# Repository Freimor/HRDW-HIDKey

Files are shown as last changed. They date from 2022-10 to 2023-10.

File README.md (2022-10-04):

## HID Key
A HID device for loadout system with a setup script. Made for the OPS team of School 21. This device allows to easily set up new workstations with just one keychain-like device. Before that the team used Arduino Micro with a bulky case and a usb cable. That device connects to MAC via Type-C, it is protected from electrostatic discharge, has an additional programmable button, an RGB LED and is very small in size.

The project is completed in Q3 2021.

 

## Parameters for PCB order (JLCPCB compatible)
2 layer board

0.8mm thickness

0.3mm min hole size

## BOM list
| №  | Designator | Qty | Description | Manufacturer | Name | Package | Link |
| -- | --- | --- | --- | --- | --- | --- | ---- |
| 1  | C1 | 1 | 10uf MLCC | | | 0402 | |
| 2  | C2,C3 | 2 | 14pf MLCC | | | 0402 | |
| 3  | C4,C5,C7,C9,C10 | 5 | 100nf MLCC | | | 0402 | |
| 4  | C6,C8 | 2 | 1uf MLCC | | | 0402 | |
| 5  | R1 | 1 | 1MΩ smd | | | 0402 | |
| 6  | R2 | 1 | 5.1kΩ smd | | | 0402 | |
| 7  | R3,R4 | 2 | 22Ω smd | | | 0402 | |
| 8  | R5,R6,R12 | 3 | 10kΩ smd | | | 0402 | |
| 9  | R7,R8,R9,R10,R11| 5 | 1kΩ smd | | | 0402 | |
| 10 | D1 | 1 | ESD protection chip | Nexperia | IP4220CZ6 | TSOP6 | |
| 11 | D2 | 1 | Yellow smd led | | | 0402 | |
| 12 | D3 | 1 | Green smd led | | | 0402 | |
| 13 | D4 | 1 | RGB smd led | Foshan NationStar | FM-B2020RGBA-HG| 2020 | |
| 14 | J1 | 1 | USB Type-C 24pin | XKB Connectivity  | U261-241N-4BS60| | |
| 15 | SW1, SW2 | 2 | Tactile switch | KLS Electronic | KLS7-TS5401 | | |
| 16 | U1 | 1 | 8bit microcontroller| Atmel | ATmega32u4 | QFN44 | |
| 17 | Y1 | 1 | 16mhz crystal | CREC | | SMD02520C4| |

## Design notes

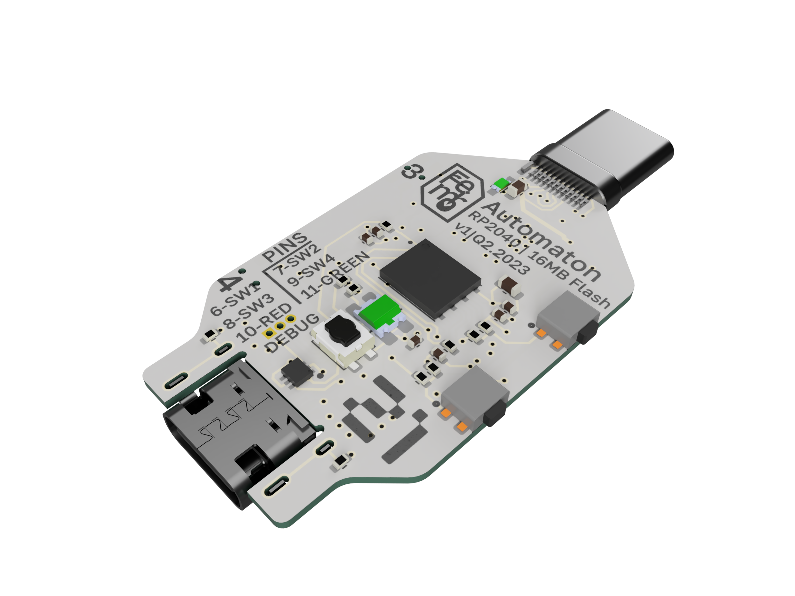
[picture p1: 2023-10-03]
KiCad/HID_Key_v2/usbduck_render_back.png

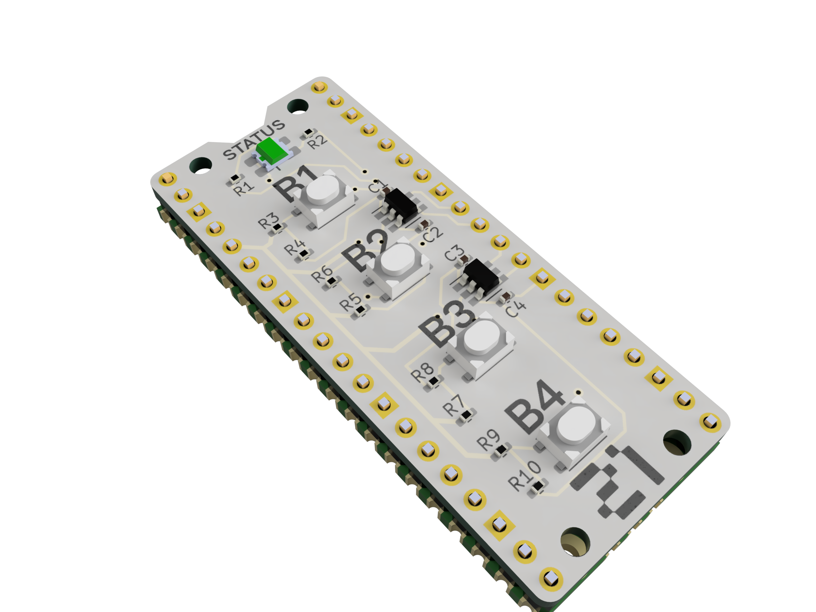
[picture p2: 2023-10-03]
KiCad/HID_Key_PicoMod/Pico_mod_render_1.PNG

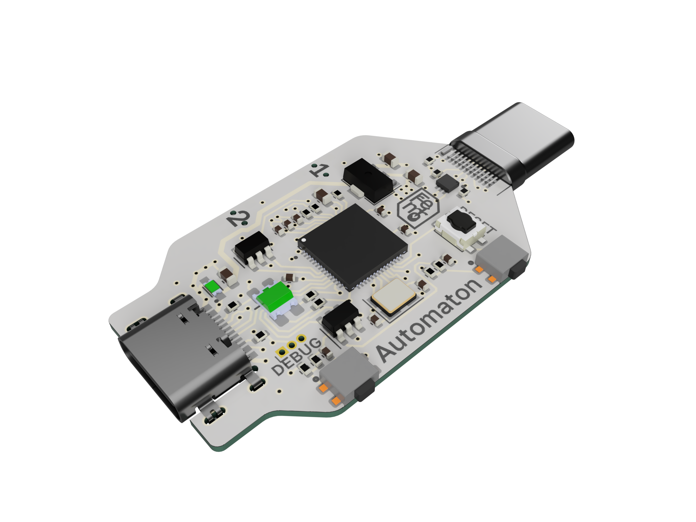
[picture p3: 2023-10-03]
KiCad/HID_Key_v2/usbduck_render_front.PNG

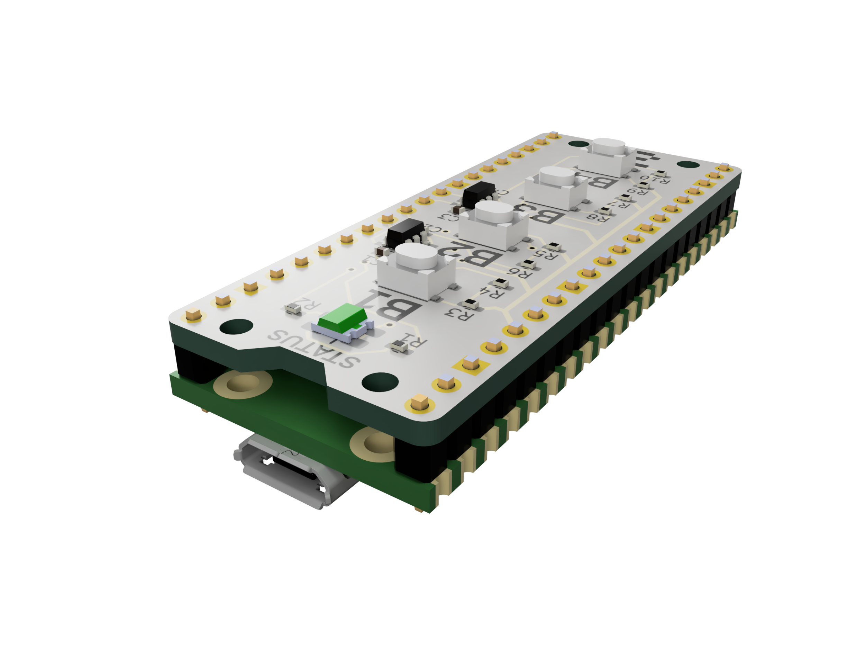
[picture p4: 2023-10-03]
KiCad/HID_Key_PicoMod/Pico_mod_render_2.png

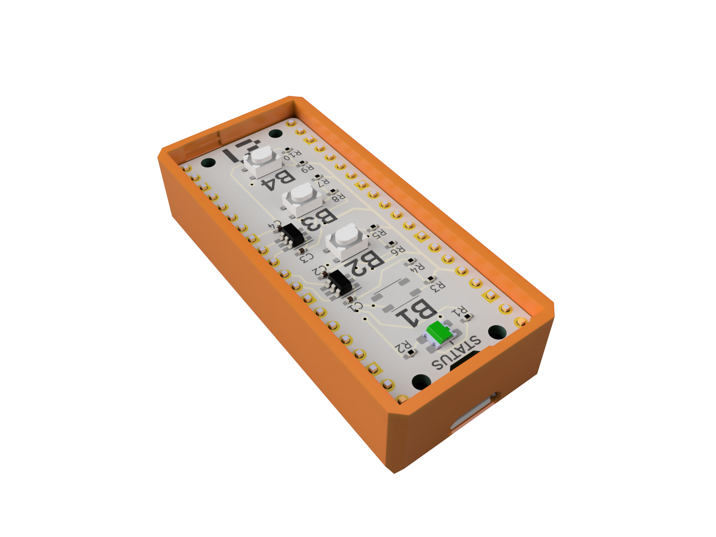
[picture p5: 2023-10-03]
KiCad/HID_Key_PicoMod/Pico_mod_render_3.png

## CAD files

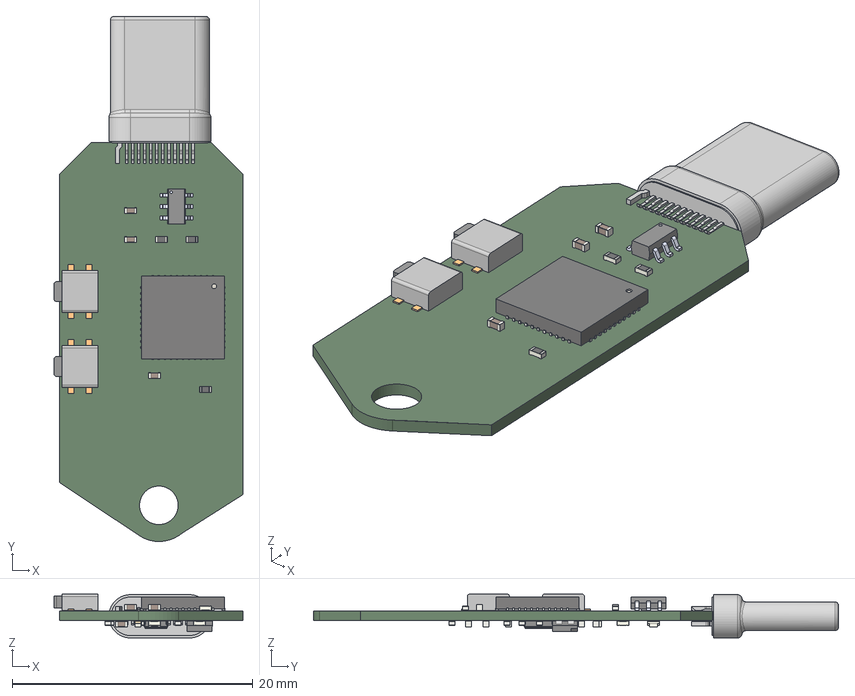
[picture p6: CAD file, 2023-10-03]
3d Model/HIDKey_v1.step
15.7 x 43.6 x 3.65 mm
Bocal_HIDKey PCB

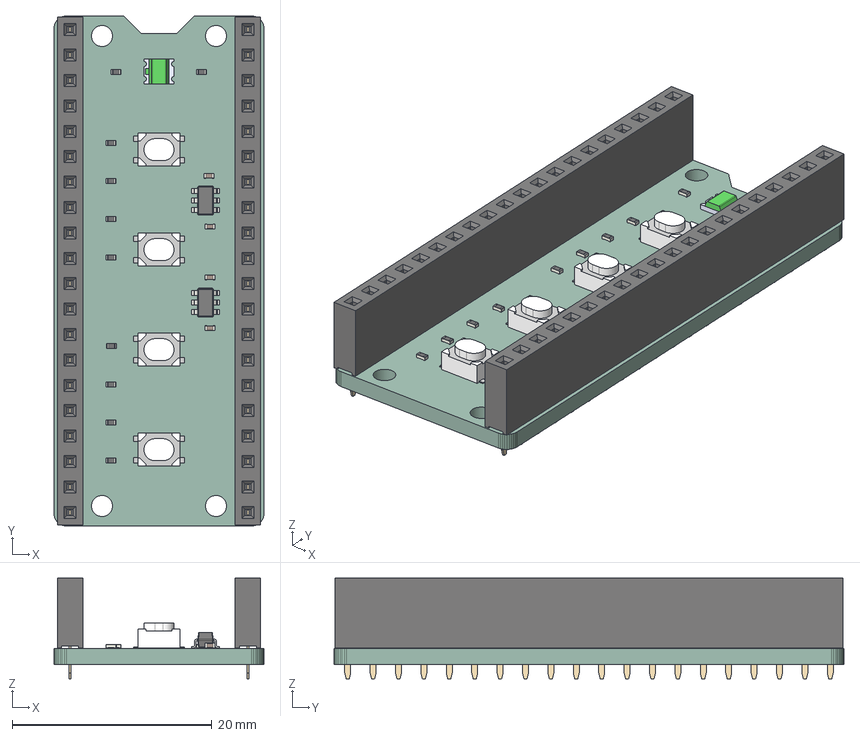
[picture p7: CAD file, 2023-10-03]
KiCad/HID_Key_PicoMod/Pico_mod.step
21.0 x 51.0 x 10.1 mm
Pico_mod PCB

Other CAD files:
3d Model/HIDKey_v1.f3d
3d Model/HIDKey_v2.f3d

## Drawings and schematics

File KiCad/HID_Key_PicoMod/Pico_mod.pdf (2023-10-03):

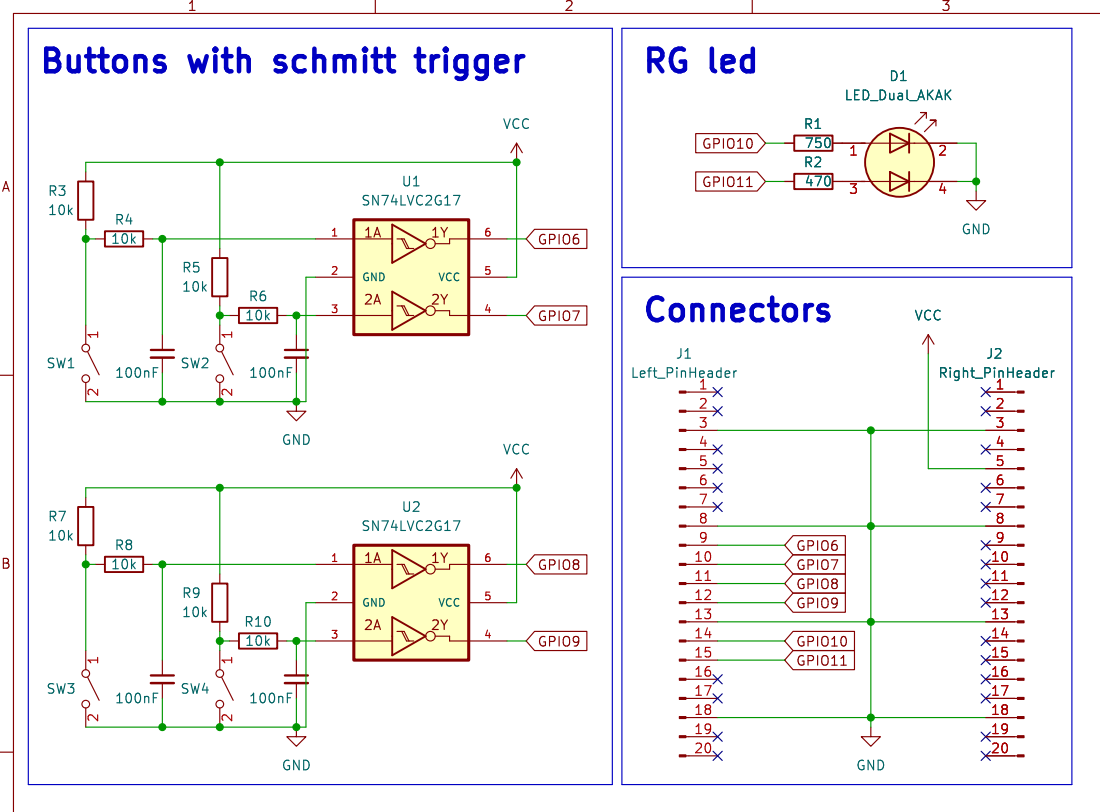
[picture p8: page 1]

Id: 1/1 Title: File: Pico_mod.kicad_sch Sheet: /

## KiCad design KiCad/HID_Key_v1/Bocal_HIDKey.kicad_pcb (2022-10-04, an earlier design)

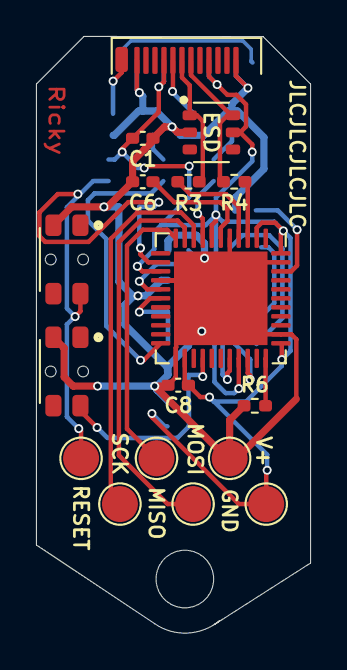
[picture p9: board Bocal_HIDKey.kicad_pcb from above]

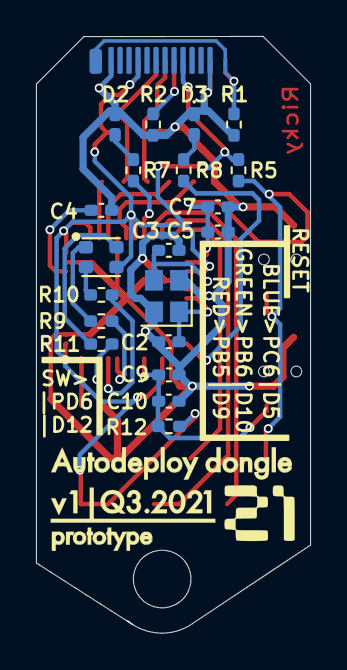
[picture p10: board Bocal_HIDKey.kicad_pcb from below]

Board: 2 copper layers, 15.2 x 33.1 mm, 37 parts (20 on the bottom side), 28 nets.

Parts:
C1: 10uF; C_0402_1005Metric_Pad0.74x0.62mm_HandSolder
C2, C3: 14pF; C_0402_1005Metric_Pad0.74x0.62mm_HandSolder
C4, C5, C7, C9, C10: 100n; C_0402_1005Metric_Pad0.74x0.62mm_HandSolder
C6, C8: 1uF; C_0402_1005Metric_Pad0.74x0.62mm_HandSolder
D1: IP4220CZ6
D2: RXLED; LED_0402_1005Metric_Pad0.77x0.64mm_HandSolder
D3: TXLED; LED_0402_1005Metric_Pad0.77x0.64mm_HandSolder
D4: LED_RBAG; LED_RGB_FM-B2020RGBA-HG
GND: test_pad_circle2mm; Pad_test
J1: USB_C_Receptacle_USB2.0; USB_C_U261-24XN-4BS60
MISO: test_pad_circle2mm; Pad_test
MOSI: test_pad_circle2mm; Pad_test
R1: 1M; R_0402_1005Metric_Pad0.72x0.64mm_HandSolder
R2: 5K1; R_0402_1005Metric_Pad0.72x0.64mm_HandSolder
R3, R4: 22; R_0402_1005Metric_Pad0.72x0.64mm_HandSolder
R5, R6, R12: 10K; R_0402_1005Metric_Pad0.72x0.64mm_HandSolder
R7, R8, R9, R10, R11: 1K; R_0402_1005Metric_Pad0.72x0.64mm_HandSolder
RESET: test_pad_circle2mm; Pad_test
SCK: test_pad_circle2mm; Pad_test
SW1: RESET_SW; TacSW_KLS7-TS5401
SW2: USER_SW; TacSW_KLS7-TS5401
U1: ATmega32U4-MU; QFN-44-1EP_7x7mm_P0.5mm_EP5.2x5.2mm
V+: test_pad_circle2mm; Pad_test
Y1: Crystal_GND24_Small; Crystal_SMD_2520-4Pin_2.5x2.0mm

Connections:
D+: D1.1, J1.A6, R3.2
D-: D1.6, J1.A7, R4.2
GND: C1.2, C2.2, C3.2, C4.2, C5.1, C6.2, C7.1, C8.2, C9.1, C10.1, D1.2, D2.1 (K), D3.1 (K), GND.1, J1.A1, J1.A12, J1.B1, J1.B12, R1.1, R2.2, R6.1, SW1.3, SW2.3, U1.5 (UGND), U1.15 (GND), U1.23 (GND), U1.35 (GND), U1.43 (GND), U1.45 (GND), Y1.2, Y1.4
MISO: MISO.1, U1.11 (PB3)
MOSI: MOSI.1, U1.10 (PB2)
unnamed: C2.1, U1.17 (XTAL1), Y1.1
unnamed: C3.1, U1.16 (XTAL2), Y1.3
unnamed: C4.1, U1.42 (AREF)
unnamed: C6.1, U1.6 (UCAP)
unnamed: C9.2, C10.2, R12.2, SW2.2, U1.26 (PD6)
unnamed: D2.2 (A), R7.1
unnamed: D3.2 (A), R8.1
unnamed: D4.1 (RK), R9.1
unnamed: D4.2 (BK), R11.1
unnamed: D4.4 (GK), R10.1
unnamed: J1.A5, R2.1
unnamed: J1.S1, R1.2
unnamed: R3.1, U1.4 (D+)
unnamed: R4.1, U1.3 (D-)
unnamed: R6.2, U1.33 (~HWB/PE2)
unnamed: R7.2, U1.8 (PB0)
unnamed: R8.2, U1.22 (PD5)
unnamed: R9.2, U1.29 (PB5)
unnamed: R10.2, U1.30 (PB6)
unnamed: R11.2, U1.31 (PC6)
RESET: C5.2, C7.2, R5.2, RESET.1, SW1.2, U1.13 (~RESET)
SCK: SCK.1, U1.9 (PB1)
VBUS: C1.1, C8.1, D1.5, D4.3 (A), J1.A4, J1.A9, J1.B4, J1.B9, R5.1, R12.1, U1.2 (UVCC), U1.7 (VBUS), U1.14 (VCC), U1.24 (AVCC), U1.34 (VCC), U1.44 (AVCC), V+.1

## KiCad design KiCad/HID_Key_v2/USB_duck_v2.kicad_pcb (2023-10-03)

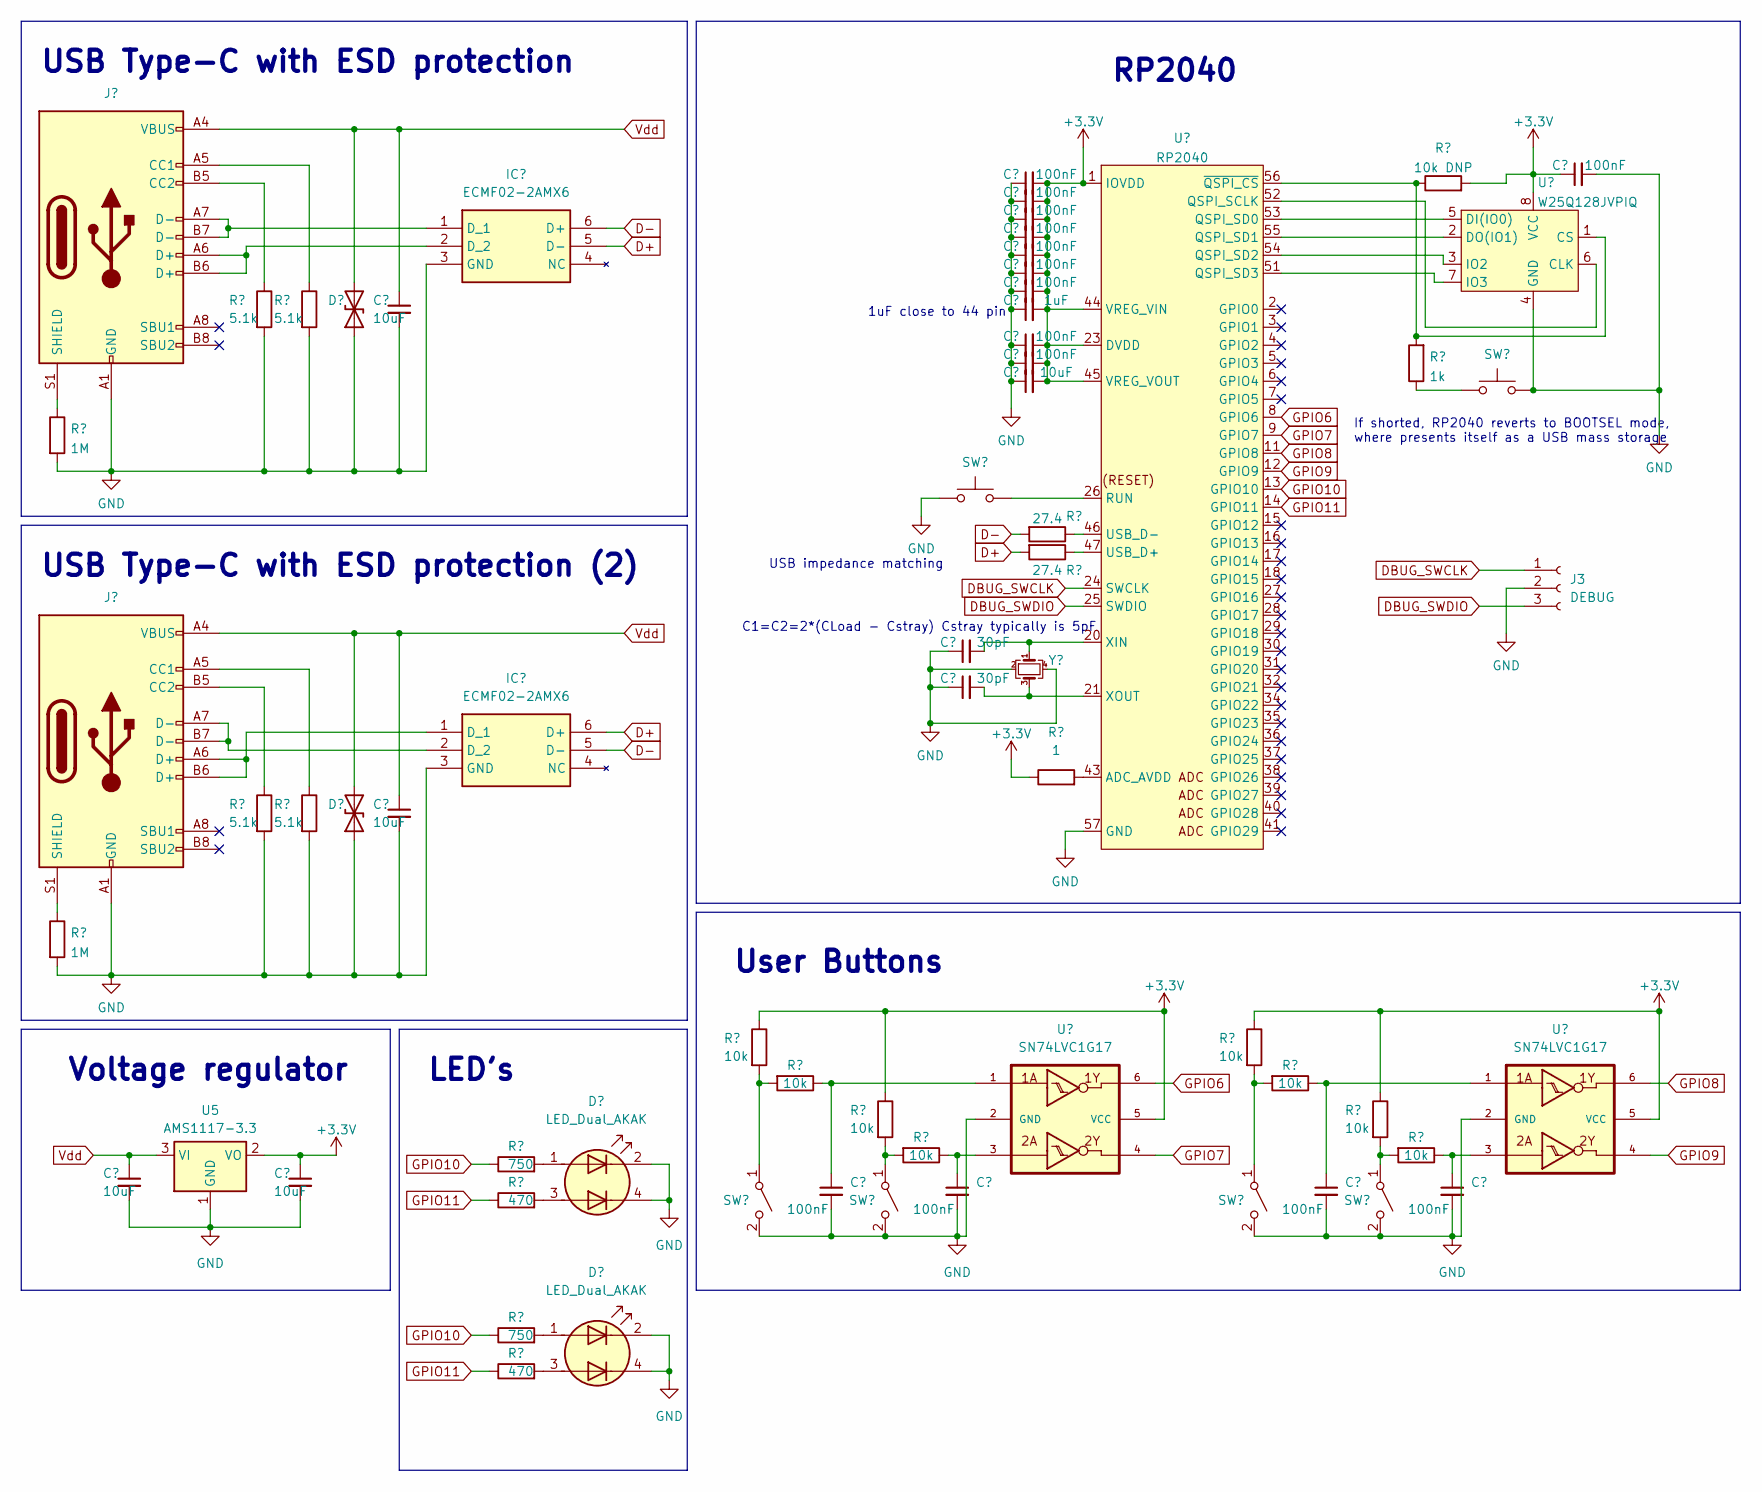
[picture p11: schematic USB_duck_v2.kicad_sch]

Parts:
BOOTSEL1: BOOTSEL; SW_SMD_XKB_(TS-1809SM-C)
C1, C2, C3, C4, C5, C6, C7, C8, C11, C12, C19, C20, C21, C22: 100nF; C_0402_1005Metric
C9, C13, C16, C17, C18: 10uF; C_0603_1608Metric
C10: 1uF; C_0603_1608Metric
C14, C15: 30pF; C_0402_1005Metric
D1, D2: D_TVS; ESD_PGB1010603MR
D3, D4: LED_Dual_AKAK; LED_RG_KPB-3025
IC1, IC2: ECMF02-2AMX6; ESD_ECMF02-2AMX6; Manufacturer_Part_Number ECMF02-2AMX6; Mouser Part Number 511-ECMF02-2AMX6
J1: USB_C_Receptacle_USB2.0; XKB_TYPE-C-U261-241N-4BS60
J2: USB_C_Receptacle_USB2.0; GCT_TYPE-C-USB4505-03-0-A
J3: DEBUG; PinHeader_1x03_P1.00mm_Vertical
R1: 10k DNP; R_0402_1005Metric
R2, R3, R9, R10: 5.1k; R_0402_1005Metric
R4: 1k; R_0402_1005Metric
R5, R11: 1M; R_0402_1005Metric
R6, R7: 27.4; R_0402_1005Metric
R8: 1; R_0402_1005Metric
R12, R13, R14, R15, R16, R17, R18, R19: 10k; R_0402_1005Metric
R20, R22: 750; R_0402_1005Metric
R21, R23: 470; R_0402_1005Metric
SW1: SW_Push; SW_SMD_XKB_(TS-1809SM-C)
SW2, SW3, SW4, SW5: SW_SPST; SW_SMD_KLS7-TS5401
U1: RP2040; MK_RP2040
U2: W25Q128JVPIQ; FLASH_W25Q128JVPIQ
U3, U4: SN74LVC1G17; SOT-23-6
U5: AMS1117-3.3; SOT-89-3
Y1: Crystal_GND24_Small; Crystal_SMD_3225-4Pin_3.2x2.5mm

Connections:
+3V3: C1.1, C2.2, C3.2, C4.2, C5.2, C6.2, C7.2, C8.2, C10.2, C11.2, C12.2, C13.2, C18.1, R1.2, R8.1, R12.1, R13.1, R16.1, R17.1, U1.1 (IOVDD), U1.10 (IOVDD), U1.22 (IOVDD), U1.23 (DVDD), U1.33 (IOVDD), U1.42 (IOVDD), U1.44 (VREG_VIN), U1.45 (VREG_VOUT), U1.48 (USB_VDD), U1.49 (IOVDD), U1.50 (DVDD), U2.8 (VCC), U3.5 (VCC), U4.5 (VCC), U5.2 (VO)
D+: IC1.5 (D-), IC2.6 (D+), R7.2
D-: IC1.6 (D+), IC2.5 (D-), R6.2
DBUG_SWCLK: J3.1, U1.24 (SWCLK)
DBUG_SWDIO: J3.3, U1.25 (SWDIO)
GND: BOOTSEL1.2, C1.2, C2.1, C3.1, C4.1, C5.1, C6.1, C7.1, C8.1, C9.2, C10.1, C11.1, C12.1, C13.1, C14.1, C15.1, C16.2, C17.2, C18.2, C19.2, C20.2, C21.2, C22.2, D1.1 (A1), D2.1 (A1), D3.2 (K1), D3.4 (K2), D4.2 (K1), D4.4 (K2), IC1.3 (GND), IC2.3 (GND), J1.A1 (GND), J1.A12 (GND), J1.B1 (GND), J1.B12 (GND), J2.A1 (GND), J2.A12 (GND), J2.B1 (GND), J2.B12 (GND), J3.2, R2.2, R3.2, R5.2, R9.2, R10.2, R11.2, SW1.1, SW2.2 (B), SW3.2 (B), SW4.2 (B), SW5.2 (B), U1.19 (TESTEN), U1.57 (GND), U2.4 (GND), U3.2 (GND), U4.2 (GND), U5.1 (GND), Y1.2, Y1.4; also elsewhere on the board
GPIO6: U1.8 (GPIO6), U3.6
GPIO7: U1.9 (GPIO7), U3.4
GPIO8: U1.11 (GPIO8), U4.6
GPIO9: U1.12 (GPIO9), U4.4
GPIO10: R20.1, R22.1, U1.13 (GPIO10)
GPIO11: R21.1, R23.1, U1.14 (GPIO11)
unnamed: BOOTSEL1.1, R4.1
unnamed: C19.1, R14.1, U3.1
unnamed: C20.1, R18.1, U3.3
unnamed: C21.1, R15.1, U4.1
unnamed: C22.1, R19.1, U4.3
unnamed: D3.1 (A1), R20.2
unnamed: D3.3 (A2), R21.2
unnamed: D4.1 (A1), R22.2
unnamed: D4.3 (A2), R23.2
unnamed: IC1.1 (D_1), J1.A7 (D-), J1.B7 (D-)
unnamed: IC1.2 (D_2), J1.A6 (D+), J1.B6 (D+)
unnamed: IC2.1 (D_1), J2.A6 (D+), J2.B6 (D+)
unnamed: IC2.2 (D_2), J2.A7 (D-), J2.B7 (D-)
unnamed: J1.A5 (CC1), R3.1
unnamed: J1.B5 (CC2), R2.1
unnamed: J1.S1 (SHIELD), R5.1
unnamed: J2.A5 (CC1), R10.1
unnamed: J2.B5 (CC2), R9.1
unnamed 30: J2.S1 (SHIELD), R11.1; also elsewhere on the board
unnamed: R12.2, R14.2, SW2.1 (A)
unnamed: R16.2, R18.2, SW3.1 (A)
unnamed: R13.2, R15.2, SW4.1 (A)
unnamed: R17.2, R19.2, SW5.1 (A)
unnamed: R8.2, U1.43 (ADC_AVDD)
unnamed: U1.52 (QSPI_SCLK), U2.6 (CLK)
unnamed: U1.53 (QSPI_SD0), U2.5 (DI(IO0))
unnamed: U1.55 (QSPI_SD1), U2.2 (DO(IO1))
unnamed: U1.54 (QSPI_SD2), U2.3 (IO2)
unnamed: U1.51 (QSPI_SD3), U2.7 (IO3)
unnamed: SW1.2, U1.26 (RUN)
unnamed: R7.1, U1.47 (USB_D+)
unnamed: R6.1, U1.46 (USB_D-)
unnamed: C14.2, U1.20 (XIN), Y1.1
unnamed: C15.2, U1.21 (XOUT), Y1.3
unnamed: R1.1, R4.2, U1.56 (~QSPI_CS), U2.1 (CS)
Vdd: C9.1, C16.1, C17.1, D1.2 (A2), D2.2 (A2), J1.A4 (VBUS), J1.A9 (VBUS), J1.B4 (VBUS), J1.B9 (VBUS), J2.A4 (VBUS), J2.A9 (VBUS), J2.B4 (VBUS), J2.B9 (VBUS), U5.3 (VI)

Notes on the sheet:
USB impedance matching
USB Type-C with ESD protection (2)
USB Type-C with ESD protection
Voltage regulator
LED's
1uF close to 44 pin
If shorted, RP2040 reverts to BOOTSEL mode, where presents itself as a USB mass storage
User Buttons
RP2040
C1=C2=2*(CLoad - Cstray) Cstray typically is 5pF

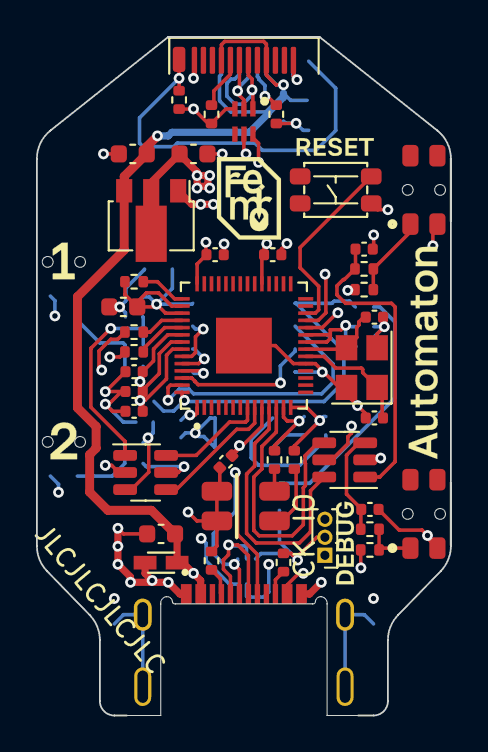
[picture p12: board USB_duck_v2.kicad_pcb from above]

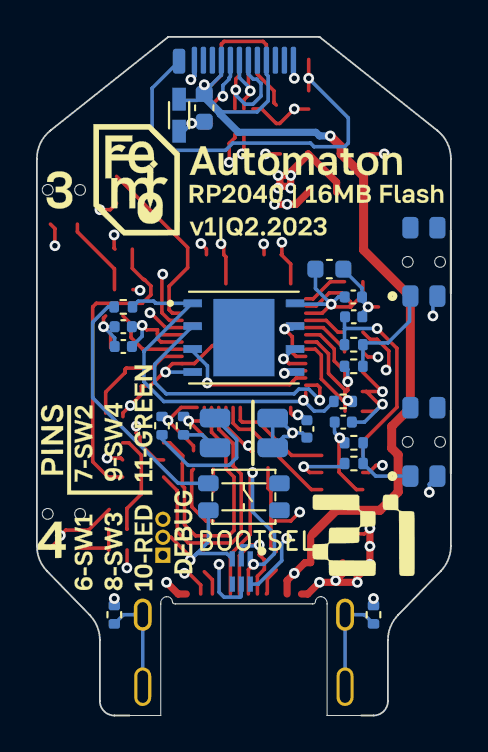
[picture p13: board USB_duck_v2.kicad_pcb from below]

Board: 4 copper layers, 23.0 x 37.7 mm, 69 parts (25 on the bottom side), 48 nets.

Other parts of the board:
R11#2: 1M; R_0402_1005Metric
Ref**: Val**; front
Ref**#2: Val**; back

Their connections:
GND: R11#2.2; also elsewhere on the board
unnamed 30: R11#2.1; also elsewhere on the board

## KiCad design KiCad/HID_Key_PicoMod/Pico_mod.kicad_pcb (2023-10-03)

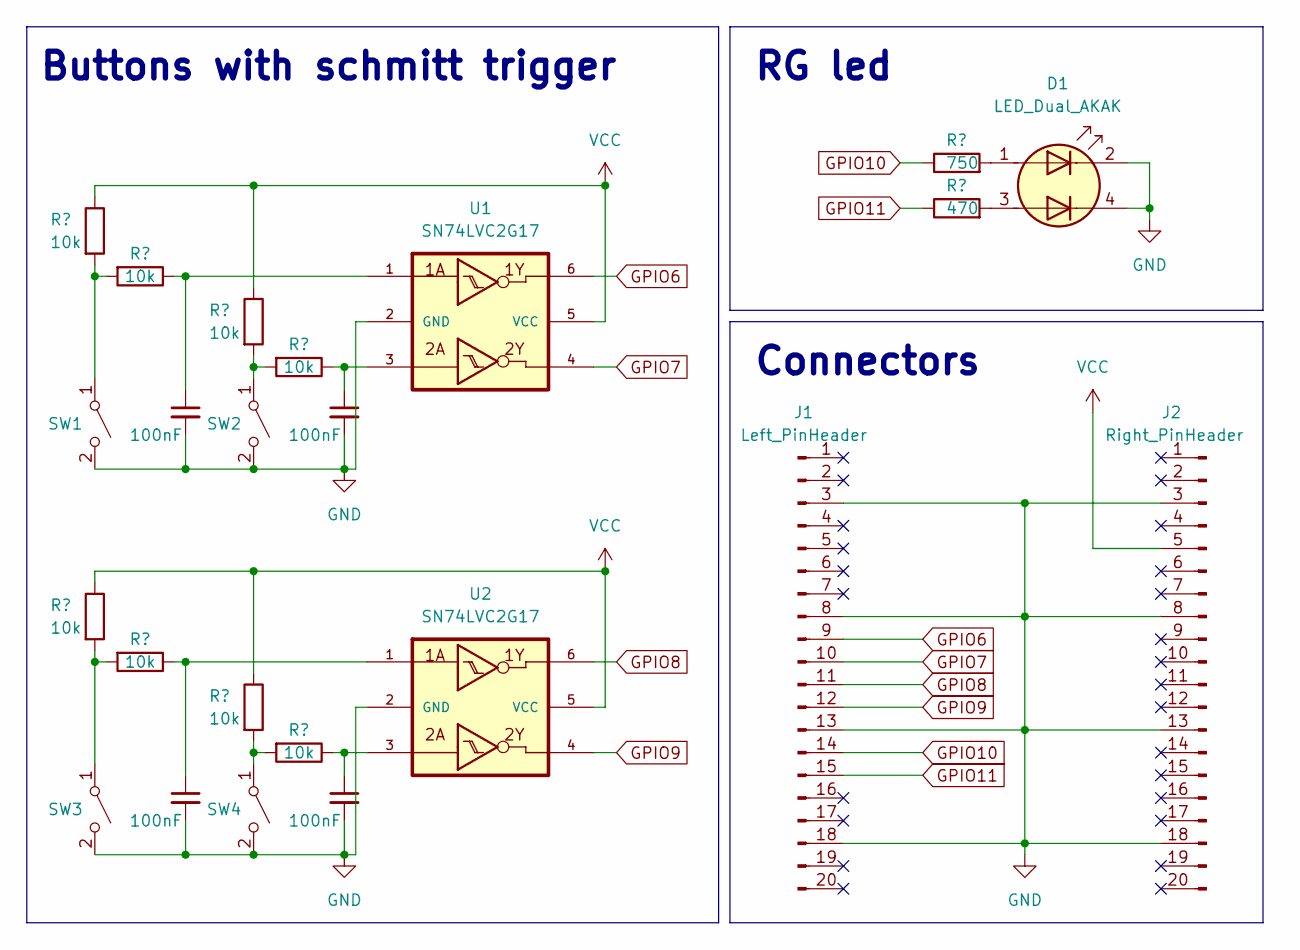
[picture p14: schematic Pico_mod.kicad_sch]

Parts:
C1, C2, C3, C4: 100nF; C_0402_1005Metric_Pad0.74x0.62mm_HandSolder
D1: LED_Dual_AKAK; LED_RG_KPB-3025
J1: Left_PinHeader; PinSocket_1x20_P2.54mm_Vertical
J2: Right_PinHeader; PinSocket_1x20_P2.54mm_Vertical
R1: 750; R_0402_1005Metric_Pad0.72x0.64mm_HandSolder
R2: 470; R_0402_1005Metric_Pad0.72x0.64mm_HandSolder
R3, R4, R5, R6, R7, R8, R9, R10: 10k; R_0402_1005Metric_Pad0.72x0.64mm_HandSolder
SW1, SW2, SW3, SW4: SW_SPST; SW_SMD_KLS7-ST3401
U1, U2: SN74LVC2G17; SOT-23-6_Handsoldering

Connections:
GND: C1.2, C2.2, C3.2, C4.2, D1.2 (K1), D1.4 (K2), J1.3, J1.8, J1.13, J1.18, J2.3, J2.8, J2.13, J2.18, SW1.2 (B), SW2.2 (B), SW3.2 (B), SW4.2 (B), U1.2 (GND), U2.2 (GND)
GPIO6: J1.9, U1.6
GPIO7: J1.10, U1.4
GPIO8: J1.11, U2.6
GPIO9: J1.12, U2.4
GPIO10: J1.14, R1.1
GPIO11: J1.15, R2.1
unnamed: C1.1, R4.1, U1.1
unnamed: C2.1, R6.1, U1.3
unnamed: C3.1, R8.1, U2.1
unnamed: C4.1, R10.1, U2.3
unnamed: D1.1 (A1), R1.2
unnamed: D1.3 (A2), R2.2
unnamed: R3.2, R4.2, SW1.1 (A)
unnamed: R5.2, R6.2, SW2.1 (A)
unnamed: R7.2, R8.2, SW3.1 (A)
unnamed: R9.2, R10.2, SW4.1 (A)
VCC: J2.5, R3.1, R5.1, R7.1, R9.1, U1.5 (VCC), U2.5 (VCC)

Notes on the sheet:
Buttons with schmitt trigger
RG led
Connectors

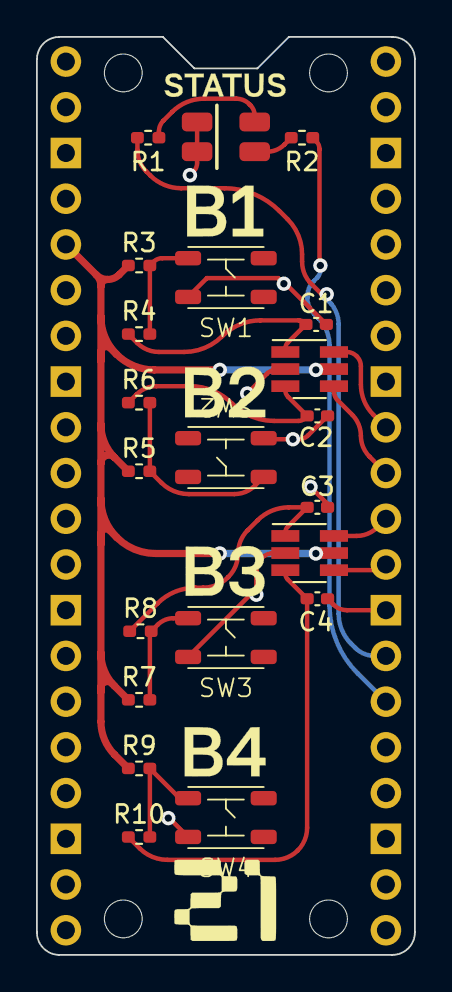
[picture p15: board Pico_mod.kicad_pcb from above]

Board: 2 copper layers, 21.0 x 51.0 mm, 24 parts (0 on the bottom side), 18 nets.

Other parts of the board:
Ref**: Val**; drawing

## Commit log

2022-10-01 Add KiCad files
    [Bocal_HIDKey.kicad_pcb, Bocal_HIDKey.kicad_sch, Bocal_HIDKey.sch]
2022-10-02 Add 3d model for preview
    [Bocal_HIDKey.stl]
2022-10-02 Update 3d preview
    [Bocal_HIDKey.stl]
2023-10-03 Q4.2023 Update
    [Bocal_HIDKey.kicad_pcb, Bocal_HIDKey.kicad_sch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]
2023-10-03 Add models
    [HIDKey_v1.f3d, HIDKey_v1.step, HIDKey_v2.f3d]
